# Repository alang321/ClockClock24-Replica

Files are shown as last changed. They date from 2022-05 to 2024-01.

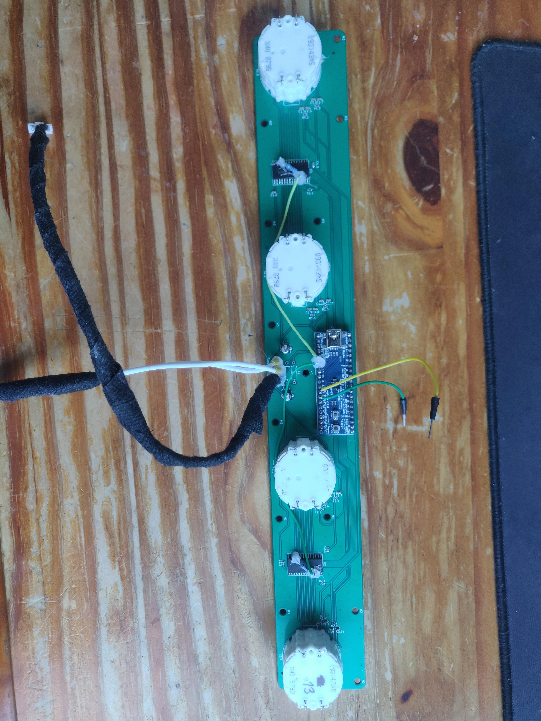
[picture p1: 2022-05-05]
Media/Photos of stepper module/module.jpg

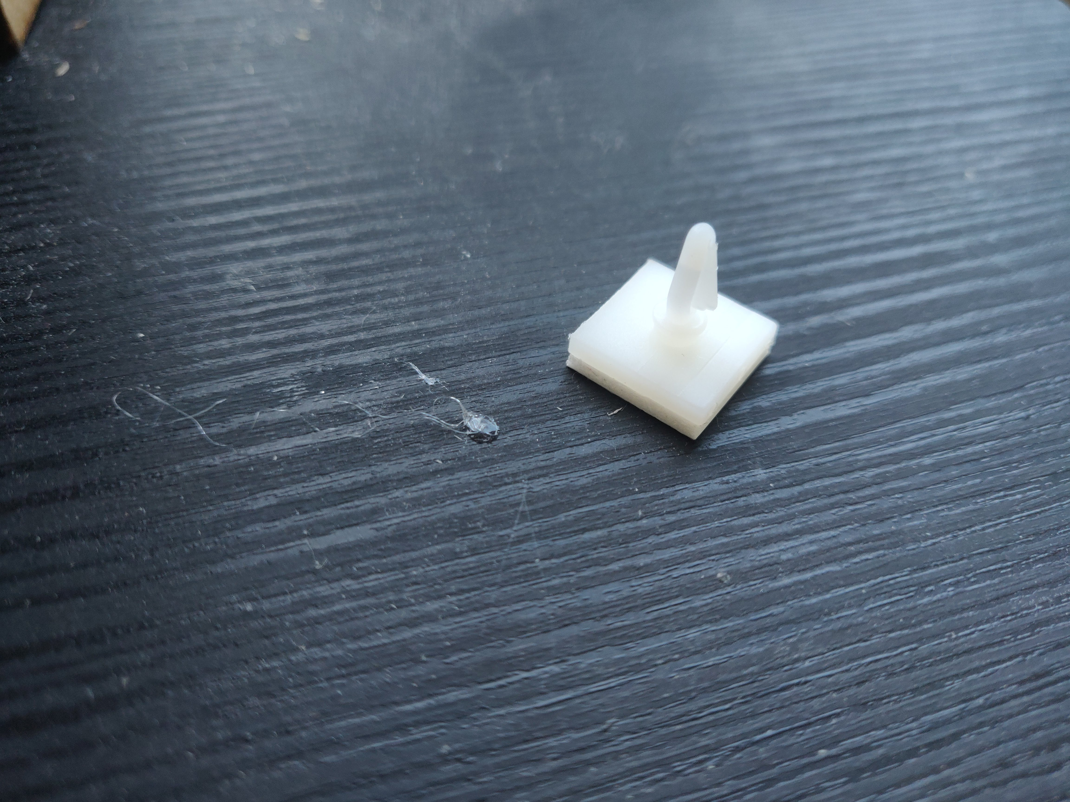
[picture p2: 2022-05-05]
Media/Photos of stepper module/pcb mount.jpg

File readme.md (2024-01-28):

# ClockClock 24 replica

Video of clock in action: https://photos.google.com/share/AF1QipM3veQpQ0XkVU6mXYjfI77cDL8gVcDZlROT0_qATZYPRnyIRZsuLHRsqtRsNTrixQ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

A clock consiting of 24 X40 stepper motors. There are 6 pcb where 4 of the X40 steppers are on a pcb. On each PCB 2 X40 (so 4 steppers, since X40 are dual axle) are controlled by a VID6606 stepper controller, so 2 VID6606 per PCB. These 2 are controlled by 1 MapleMini STM32F103. These 6 modules are controlled by a single RasberryPi Pico running MicroPython, this Pico communicates with the modules over I2C and also a DS3231 RTC for timekeeping. Additionally, as an optional addon a network model (a Pico W) can be added to get ITP time (This was added after everthing was finished so I didnt want to change the main control board to a Pico W). The clock works reliably with the newest addition of chekcsums and hasnt crashed since. Setting the time and display modes is done via a button panel of 4 buttons.

## Things to improve:
- The bus should be switched to CAN something else more robust then I2C, which is used here. I2C now works flawlessly for me but perhaps in a higher noise environment or over years errors would occur.
- Add pull down resistor for enable pin of vid 6606, connect to MCU pin (had to be botched in)
- Change microcontroller to smth cheaper/newer (RP2040?)
- Maybe switch to TMC2209 or smth for more silent driving (Some preliminary tests showed they do work with these steppers and are a bit more quiet, but they are much more expensive)

## Additional notes: 

- There was a plan to automatically zero the steppers with a small magnet and hall sensor but this was not implemented, but the sensor mountings are present on the PCB
- I lubricated the X40 steppers with SuperLube which did definitely reduce noise but this went back to normal levels after a few months.
- The main body is made of Korian which I had made by a professional using the drawing in the 3d parts folder
- Pointers where printed on a consumer FDM printer (Ender3V2) and where sanded and are friction fit.

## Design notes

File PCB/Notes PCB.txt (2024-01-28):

Things to improve:

Remove hall sensor functionality
Add can bus or smth, since i2c is not robust
Add pull down resistor for enable pin of vid 6606, connect to MCU pin
Change microcontroller to smth cheaper/newer (RP2040?)?
Add bus daisy chain connectors
Add better connector (instead of screw terminal)
Use pin 14 instead of pin 22 (if same MapleMini is used, gave some weird issues)

Maybe switch to TMC2209 or smth for more silent driving (Some preliminary tests showed they do work with these steppers and are a bit more quiet)

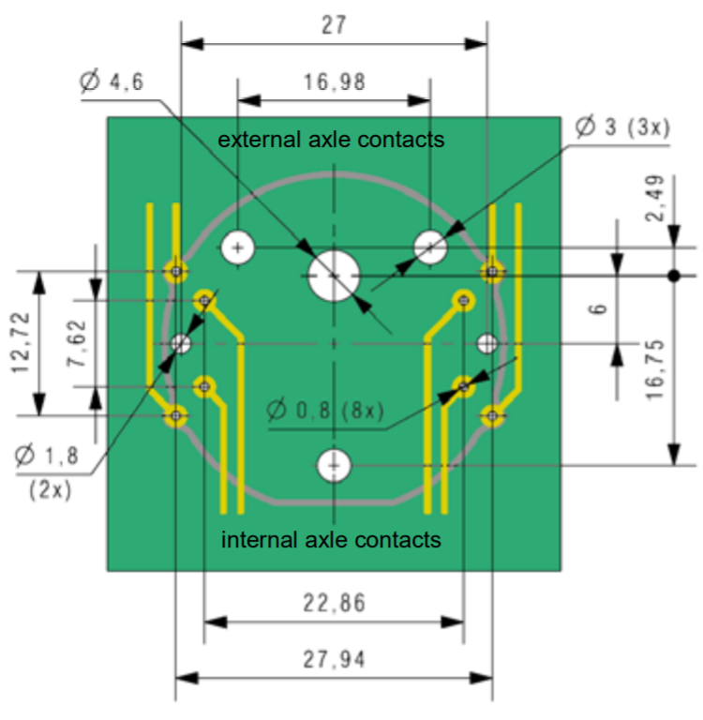
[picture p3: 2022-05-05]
Media/Reference photos/Screenshot 2021-03-22 151851.png

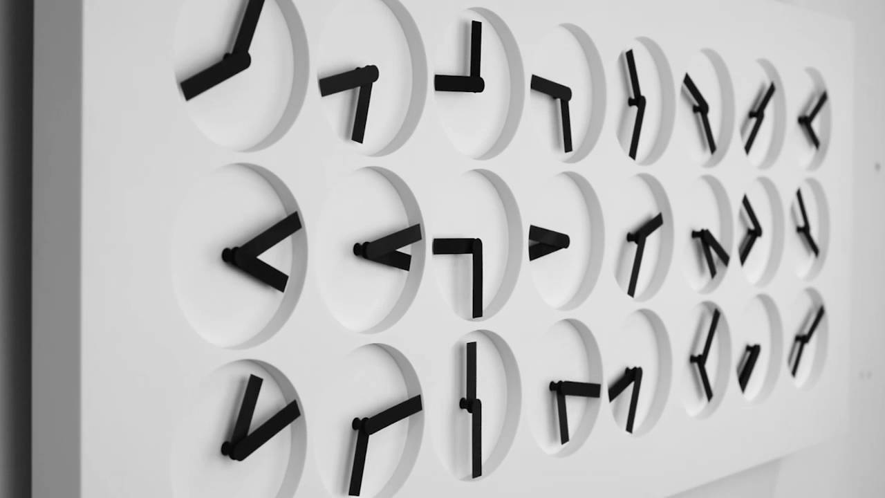
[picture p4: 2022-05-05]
Media/Reference photos/clock-clock-24-a-fascinating-kin.jpg

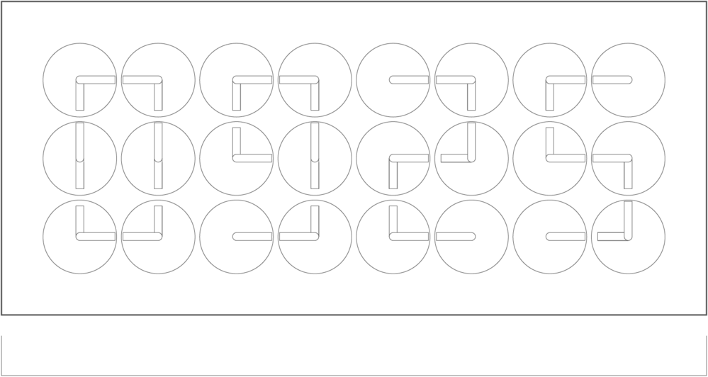
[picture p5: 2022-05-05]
Media/Reference photos/w_CC24_FRONT_spspec_900-x-400mm_1000x.png

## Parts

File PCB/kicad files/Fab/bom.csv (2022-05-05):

Comment | Designator | Footprint | LCSC Part Number
22 uF | C1.1,C2.1 | Capacitor_SMD:CP_Elec_4x5.3 | C134793
100 nF | C1.2,C1.3,C2.2,C2.3 | Capacitor_SMD:C_0603_1608Metric | C14663
4.7 nF | C1.4,C1.5,C1.6,C1.7,C1.8,C1.9,C2.4,C2.5,C2.6,C2.7,C2.8,C2.9,C1.10,C1.11,C2.10,C2.11 | Capacitor_SMD:C_0603_1608Metric | C53987
Conn_01x04_Female | J1 | Connector_PinHeader_2.54mm:PinHeader_1x04_P2.54mm_Vertical | C474922
1K2 | R1.1,R1.2,R1.3,R1.4,R1.5,R2.1,R2.2,R2.3,R2.4,R2.5 | Resistor_SMD:R_0603_1608Metric | C22765

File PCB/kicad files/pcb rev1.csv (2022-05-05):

Source: | C:\Users\muska\Desktop\pcb rev2\pcb rev1.sch
Date: | 27.05.2021 11:37:47
Tool: | Eeschema (5.1.10)-1
Generator: | C:\Program Files\KiCad\bin\scripting\plugins/bom_csv_grouped_by_value.py
Component Count: | 50
Individual Components:
Item | Qty | Reference(s) | Value | LibPart | Footprint | Datasheet | LCSC
 |  | A1 | Maple_Mini | MCU_Module:Maple_Mini | Module:Maple_Mini | http://docs.leaflabs.com/static.leaflabs.com/pub/leaflabs/maple-docs/0.0.12/hardware/maple-mini.html
 |  | C1.1 | 22 uF | Device:CP | Capacitor_SMD:CP_Elec_4x5.3 | ~ | C134793
 |  | C1.2 | 100 nF | Device:C | Capacitor_SMD:C_0603_1608Metric | ~ | C14663
 |  | C1.3 | 100 nF | Device:C | Capacitor_SMD:C_0603_1608Metric | ~ | C14663
 |  | C1.4 | 4.7 nF | Device:C | Capacitor_SMD:C_0603_1608Metric | ~ | C53987
 |  | C1.5 | 4.7 nF | Device:C | Capacitor_SMD:C_0603_1608Metric | ~ | C53987
 |  | C1.6 | 4.7 nF | Device:C | Capacitor_SMD:C_0603_1608Metric | ~ | C53987
 |  | C1.7 | 4.7 nF | Device:C | Capacitor_SMD:C_0603_1608Metric | ~ | C53987
 |  | C1.8 | 4.7 nF | Device:C | Capacitor_SMD:C_0603_1608Metric | ~ | C53987
 |  | C1.9 | 4.7 nF | Device:C | Capacitor_SMD:C_0603_1608Metric | ~ | C53987
 |  | C1.10 | 4.7 nF | Device:C | Capacitor_SMD:C_0603_1608Metric | ~ | C53987
 |  | C1.11 | 4.7 nF | Device:C | Capacitor_SMD:C_0603_1608Metric | ~ | C53987
 |  | C2.1 | 22 uF | Device:CP | Capacitor_SMD:CP_Elec_4x5.3 | ~ | C134793
 |  | C2.2 | 100 nF | Device:C | Capacitor_SMD:C_0603_1608Metric | ~ | C14663
 |  | C2.3 | 100 nF | Device:C | Capacitor_SMD:C_0603_1608Metric | ~ | C14663
 |  | C2.4 | 4.7 nF | Device:C | Capacitor_SMD:C_0603_1608Metric | ~ | C53987
 |  | C2.5 | 4.7 nF | Device:C | Capacitor_SMD:C_0603_1608Metric | ~ | C53987
 |  | C2.6 | 4.7 nF | Device:C | Capacitor_SMD:C_0603_1608Metric | ~ | C53987
 |  | C2.7 | 4.7 nF | Device:C | Capacitor_SMD:C_0603_1608Metric | ~ | C53987
 |  | C2.8 | 4.7 nF | Device:C | Capacitor_SMD:C_0603_1608Metric | ~ | C53987
 |  | C2.9 | 4.7 nF | Device:C | Capacitor_SMD:C_0603_1608Metric | ~ | C53987
 |  | C2.10 | 4.7 nF | Device:C | Capacitor_SMD:C_0603_1608Metric | ~ | C53987
 |  | C2.11 | 4.7 nF | Device:C | Capacitor_SMD:C_0603_1608Metric | ~ | C53987
 |  | H1.1L1 | TLE4905L | pcb-rev1-rescue:TLE4905L-Sensor_Magnetic | c40:PG-SSO-3-02 | https://sensing.honeywell.com/honeywell-sensing-nanopower-series-product-sheet-50095501-a-en.pdf
 |  | H1.1U1 | TLE4905L | pcb-rev1-rescue:TLE4905L-Sensor_Magnetic | c40:PG-SSO-3-02 | https://sensing.honeywell.com/honeywell-sensing-nanopower-series-product-sheet-50095501-a-en.pdf
 |  | H1.2L1 | TLE4905L | pcb-rev1-rescue:TLE4905L-Sensor_Magnetic | c40:PG-SSO-3-02 | https://sensing.honeywell.com/honeywell-sensing-nanopower-series-product-sheet-50095501-a-en.pdf
 |  | H1.2U1 | TLE4905L | pcb-rev1-rescue:TLE4905L-Sensor_Magnetic | c40:PG-SSO-3-02 | https://sensing.honeywell.com/honeywell-sensing-nanopower-series-product-sheet-50095501-a-en.pdf
 |  | H2.1L1 | TLE4905L | pcb-rev1-rescue:TLE4905L-Sensor_Magnetic | c40:PG-SSO-3-02 | https://sensing.honeywell.com/honeywell-sensing-nanopower-series-product-sheet-50095501-a-en.pdf
 |  | H2.1U1 | TLE4905L | pcb-rev1-rescue:TLE4905L-Sensor_Magnetic | c40:PG-SSO-3-02 | https://sensing.honeywell.com/honeywell-sensing-nanopower-series-product-sheet-50095501-a-en.pdf
 |  | H2.2L1 | TLE4905L | pcb-rev1-rescue:TLE4905L-Sensor_Magnetic | c40:PG-SSO-3-02 | https://sensing.honeywell.com/honeywell-sensing-nanopower-series-product-sheet-50095501-a-en.pdf
 |  | H2.2U2 | TLE4905L | pcb-rev1-rescue:TLE4905L-Sensor_Magnetic | c40:PG-SSO-3-02 | https://sensing.honeywell.com/honeywell-sensing-nanopower-series-product-sheet-50095501-a-en.pdf
 |  | J1 | Conn_01x04_Female | Connector:Conn_01x04_Female | Connector_PinHeader_2.54mm:PinHeader_1x04_P2.54mm_Vertical | ~ | C474922
 |  | R1 | 5K | Device:R | Resistor_THT:R_Axial_DIN0207_L6.3mm_D2.5mm_P10.16mm_Horizontal | ~
 |  | R1.1 | 1K2 | Device:R | Resistor_SMD:R_0603_1608Metric | ~ | C22765
 |  | R1.2 | 1K2 | Device:R | Resistor_SMD:R_0603_1608Metric | ~ | C22765
 |  | R1.3 | 1K2 | Device:R | Resistor_SMD:R_0603_1608Metric | ~ | C22765
 |  | R1.4 | 1K2 | Device:R | Resistor_SMD:R_0603_1608Metric | ~ | C22765
 |  | R1.5 | 1K2 | Device:R | Resistor_SMD:R_0603_1608Metric | ~ | C22765
 |  | R2 | 5K | Device:R | Resistor_THT:R_Axial_DIN0207_L6.3mm_D2.5mm_P10.16mm_Horizontal | ~
 |  | R2.1 | 1K2 | Device:R | Resistor_SMD:R_0603_1608Metric | ~ | C22765
 |  | R2.2 | 1K2 | Device:R | Resistor_SMD:R_0603_1608Metric | ~ | C22765
 |  | R2.3 | 1K2 | Device:R | Resistor_SMD:R_0603_1608Metric | ~ | C22765
 |  | R2.4 | 1K2 | Device:R | Resistor_SMD:R_0603_1608Metric | ~ | C22765
 |  | R2.5 | 1K2 | Device:R | Resistor_SMD:R_0603_1608Metric | ~ | C22765
 |  | U1 | VID66-06 | pcb-rev1-rescue:VID66-06-Driver_Motor | Package_SO:SOP-28
 |  | U2 | VID66-06 | pcb-rev1-rescue:VID66-06-Driver_Motor | Package_SO:SOP-28
 |  | X1.1 | X40 | pcb-rev1-rescue:X40-Driver_Motor | c40:X40
 |  | X1.2 | X40 | pcb-rev1-rescue:X40-Driver_Motor | c40:X40
 |  | X2.1 | X40 | pcb-rev1-rescue:X40-Driver_Motor | c40:X40
 |  | X2.2 | X40 | pcb-rev1-rescue:X40-Driver_Motor | c40:X40
Collated Components:
Item | Qty | Reference(s) | Value | LibPart | Footprint | Datasheet | LCSC
1 | 1 | A1 | Maple_Mini | MCU_Module:Maple_Mini | Module:Maple_Mini | http://docs.leaflabs.com/static.leaflabs.com/pub/leaflabs/maple-docs/0.0.12/hardware/maple-mini.html
2 | 2 | C1.1, C2.1 | 22 uF | Device:CP | Capacitor_SMD:CP_Elec_4x5.3 | ~ | C134793
3 | 4 | C1.2, C1.3, C2.2, C2.3 | 100 nF | Device:C | Capacitor_SMD:C_0603_1608Metric | ~ | C14663
4 | 16 | C1.4, C1.5, C1.6, C1.7, C1.8, C1.9, C1.10, C1.11, C2.4, C2.5, C2.6, C2.7, C2.8, C2.9, C2.10, C2.11 | 4.7 nF | Device:C | Capacitor_SMD:C_0603_1608Metric | ~ | C53987
5 | 8 | H1.1L1, H1.1U1, H1.2L1, H1.2U1, H2.1L1, H2.1U1, H2.2L1, H2.2U2 | TLE4905L | pcb-rev1-rescue:TLE4905L-Sensor_Magnetic | c40:PG-SSO-3-02 | https://sensing.honeywell.com/honeywell-sensing-nanopower-series-product-sheet-50095501-a-en.pdf
6 | 1 | J1 | Conn_01x04_Female | Connector:Conn_01x04_Female | Connector_PinHeader_2.54mm:PinHeader_1x04_P2.54mm_Vertical | ~ | C474922
7 | 2 | R1, R2 | 5K | Device:R | Resistor_THT:R_Axial_DIN0207_L6.3mm_D2.5mm_P10.16mm_Horizontal | ~
8 | 10 | R1.1, R1.2, R1.3, R1.4, R1.5, R2.1, R2.2, R2.3, R2.4, R2.5 | 1K2 | Device:R | Resistor_SMD:R_0603_1608Metric | ~ | C22765
9 | 2 | U1, U2 | VID66-06 | pcb-rev1-rescue:VID66-06-Driver_Motor | Package_SO:SOP-28
10 | 4 | X1.1, X1.2, X2.1, X2.2 | X40 | pcb-rev1-rescue:X40-Driver_Motor | c40:X40

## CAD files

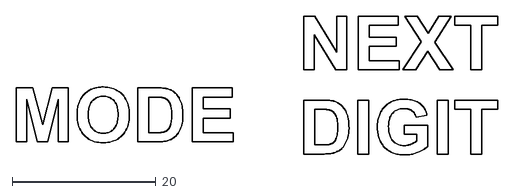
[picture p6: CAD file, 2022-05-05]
3d models/button plate/MODE.dxf
67.0 x 19.3

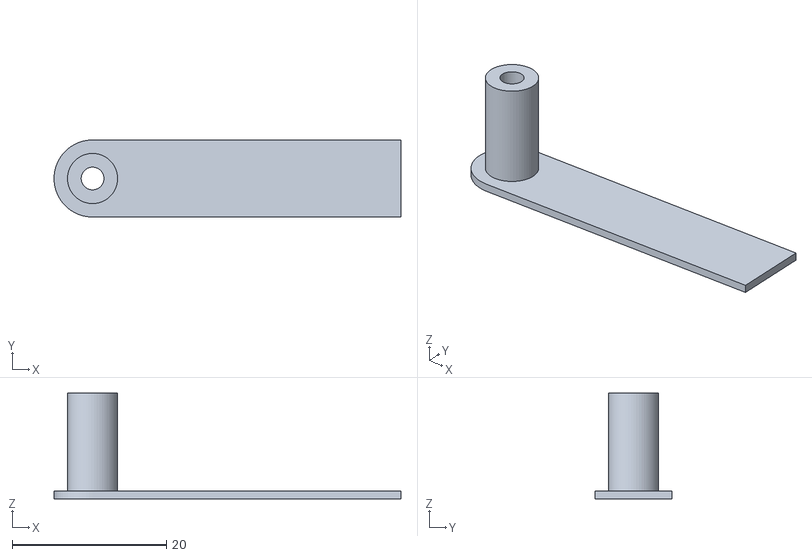
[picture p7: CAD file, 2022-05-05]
3d models/pointer/pointer HP MJF (never tested)/pointer_hour.stl
45.0 x 10.0 x 13.7

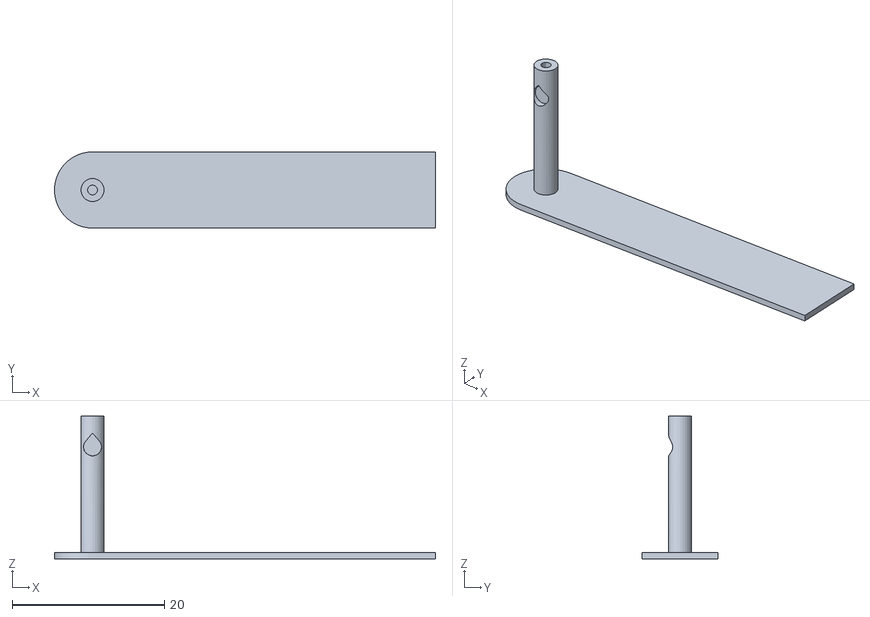
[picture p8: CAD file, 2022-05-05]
3d models/pointer/pointer resin rev 1 (never printed)/STL/minuten.stl
50.0 x 10.0 x 18.7

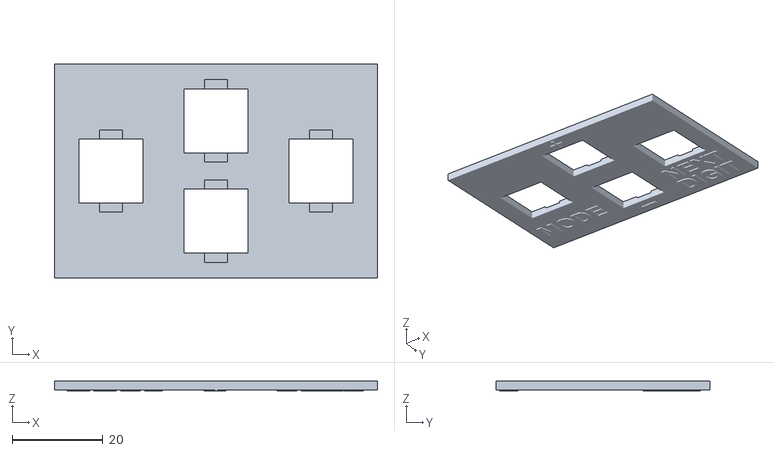
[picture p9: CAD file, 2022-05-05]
3d models/button plate/button_plate.stl
71.1 x 47.0 x 2.30

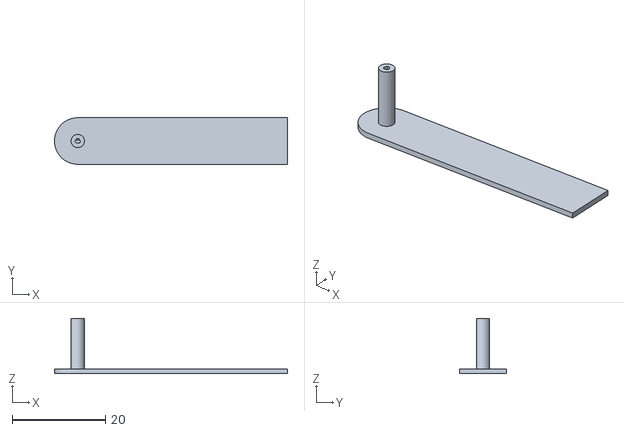
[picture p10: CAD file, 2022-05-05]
3d models/pointer/pointer HP MJF (never tested)/pointer_minute.stl
50.0 x 10.0 x 11.9

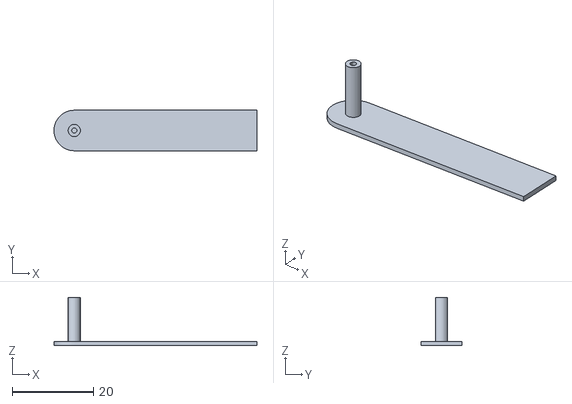
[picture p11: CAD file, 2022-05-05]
3d models/pointer/pointer no magnet (used in my version)/STL/minuten.stl
50.0 x 10.0 x 11.9

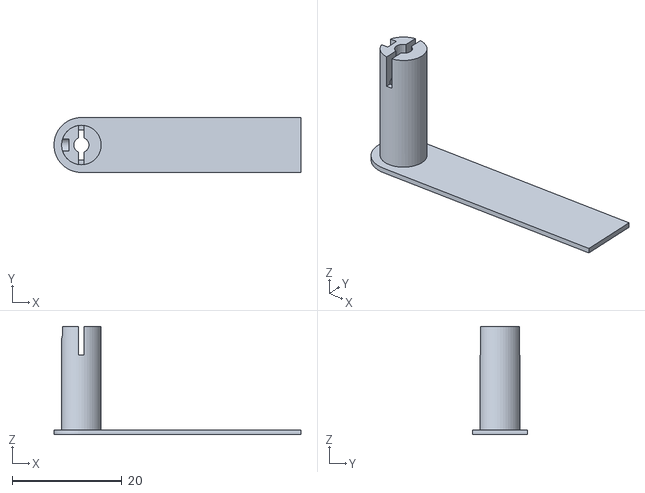
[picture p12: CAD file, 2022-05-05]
3d models/pointer/pointer resin rev 1 (never printed)/STL/stunden.stl
45.0 x 10.0 x 19.7

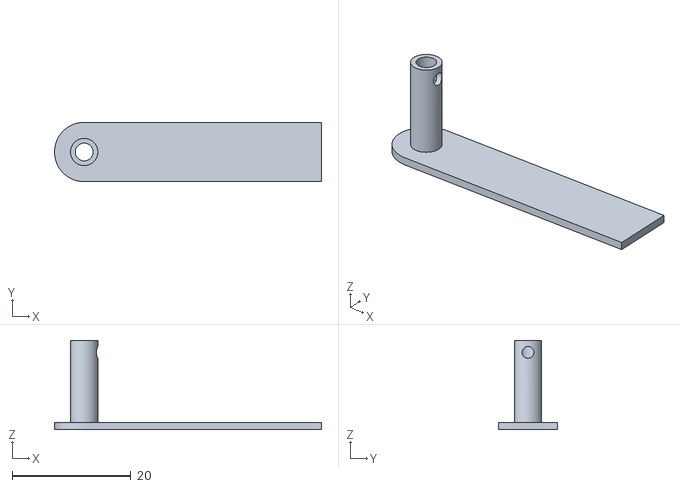
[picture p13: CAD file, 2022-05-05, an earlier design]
3d models/pointer/pointer with magnet/uhrzeiger rev 2/STL/stunden.stl
45.0 x 10.0 x 15.0

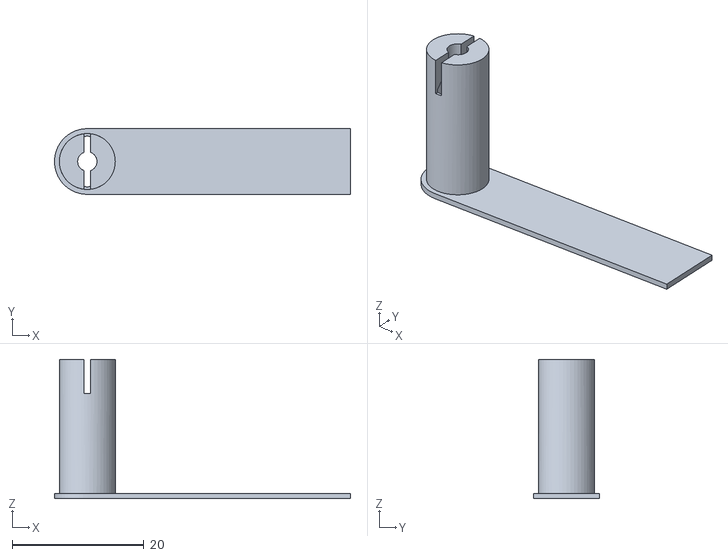
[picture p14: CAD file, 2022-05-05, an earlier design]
3d models/pointer/pointer with magnet/uhrzeiger rev 4/STL/stunden.stl
45.0 x 10.0 x 21.2

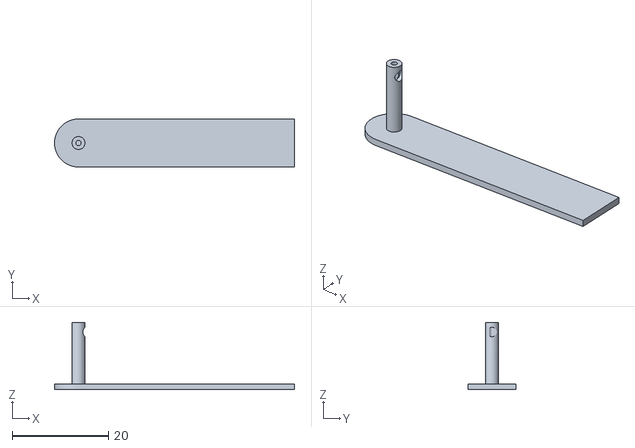
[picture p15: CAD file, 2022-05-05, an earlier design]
3d models/pointer/pointer with magnet/uhrzeiger rev 2/STL/minuten.stl
50.0 x 10.0 x 14.0

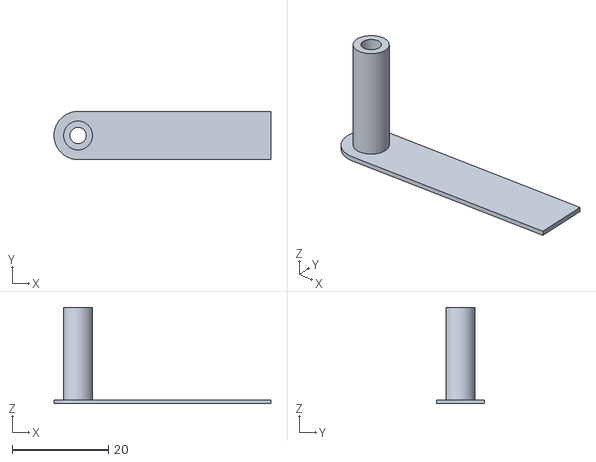
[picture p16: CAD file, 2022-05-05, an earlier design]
3d models/pointer/pointer with magnet/uhrzeiger rev 3/STL/stunden.stl
45.0 x 10.0 x 20.0

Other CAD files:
3d models/pointer/pointer no magnet (used in my version)/STL/stunden.stl
3d models/pointer/pointer with magnet/uhrzeiger rev 3/STL/minuten.stl
3d models/pointer/pointer with magnet/uhrzeiger rev 4/STL/minuten.stl
3d models/Other clock parts/Clockface with steppers and pcbs.CATProduct
3d models/Other clock parts/PCB with X40 assemblies.CATProduct
3d models/Other clock parts/Pcb.CATPart
3d models/Other clock parts/X40.CATPart
3d models/Other clock parts/clockback rim.CATPart
3d models/Other clock parts/clockface.CATPart
3d models/Other clock parts/x40 with pointers.CATProduct
3d models/button plate/plate.CATPart
3d models/pointer/pointer no magnet (used in my version)/CAD/Assembly.CATProduct
3d models/pointer/pointer no magnet (used in my version)/CAD/minuten.CATPart
3d models/pointer/pointer no magnet (used in my version)/CAD/stunden.CATPart
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

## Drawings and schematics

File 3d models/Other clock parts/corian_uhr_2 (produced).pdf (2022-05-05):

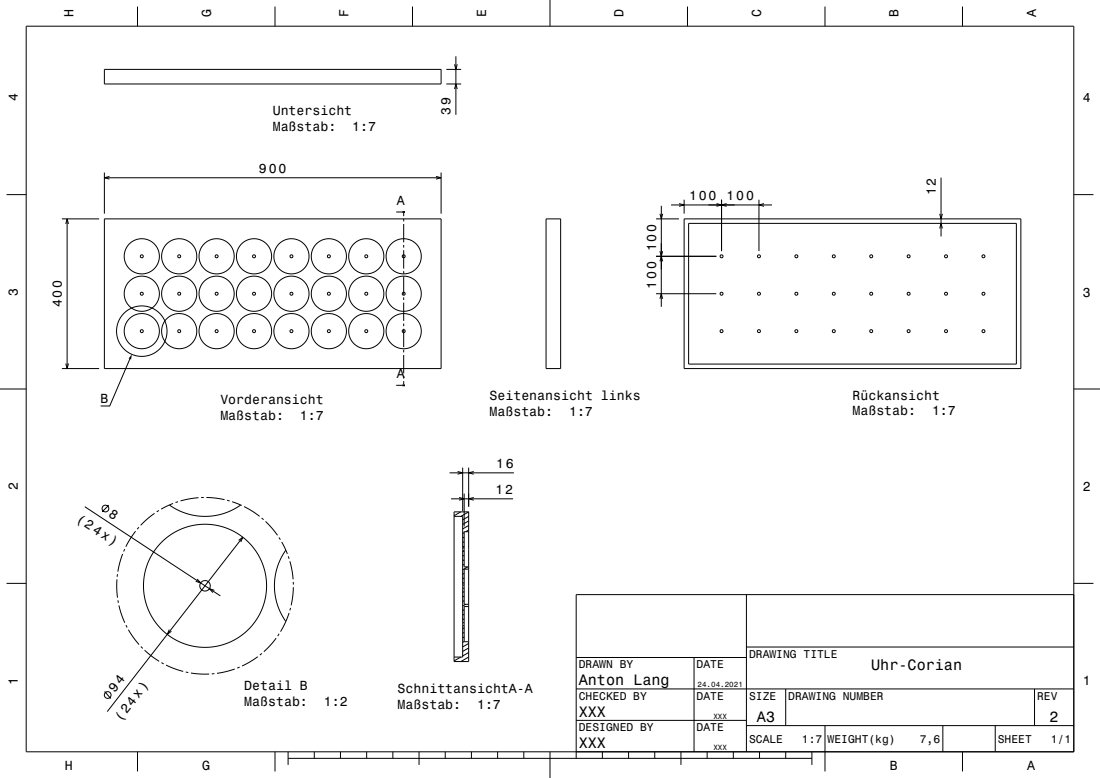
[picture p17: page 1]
DRAWING TITLE; Maßstab: 1:7; Seitenansicht links; Detail B Maßstab: 1:2

DRAWN BY Anton Lang | DATE 24.04.2021

CHECKED BY XXX | DATE XXX | SIZE A3 | DRAWING NUMBER | REV 2

DESIGNED BY XXX | DATE XXX

SCALE 1:7 | WEIGHT(kg) 7,6 | SHEET 1/1

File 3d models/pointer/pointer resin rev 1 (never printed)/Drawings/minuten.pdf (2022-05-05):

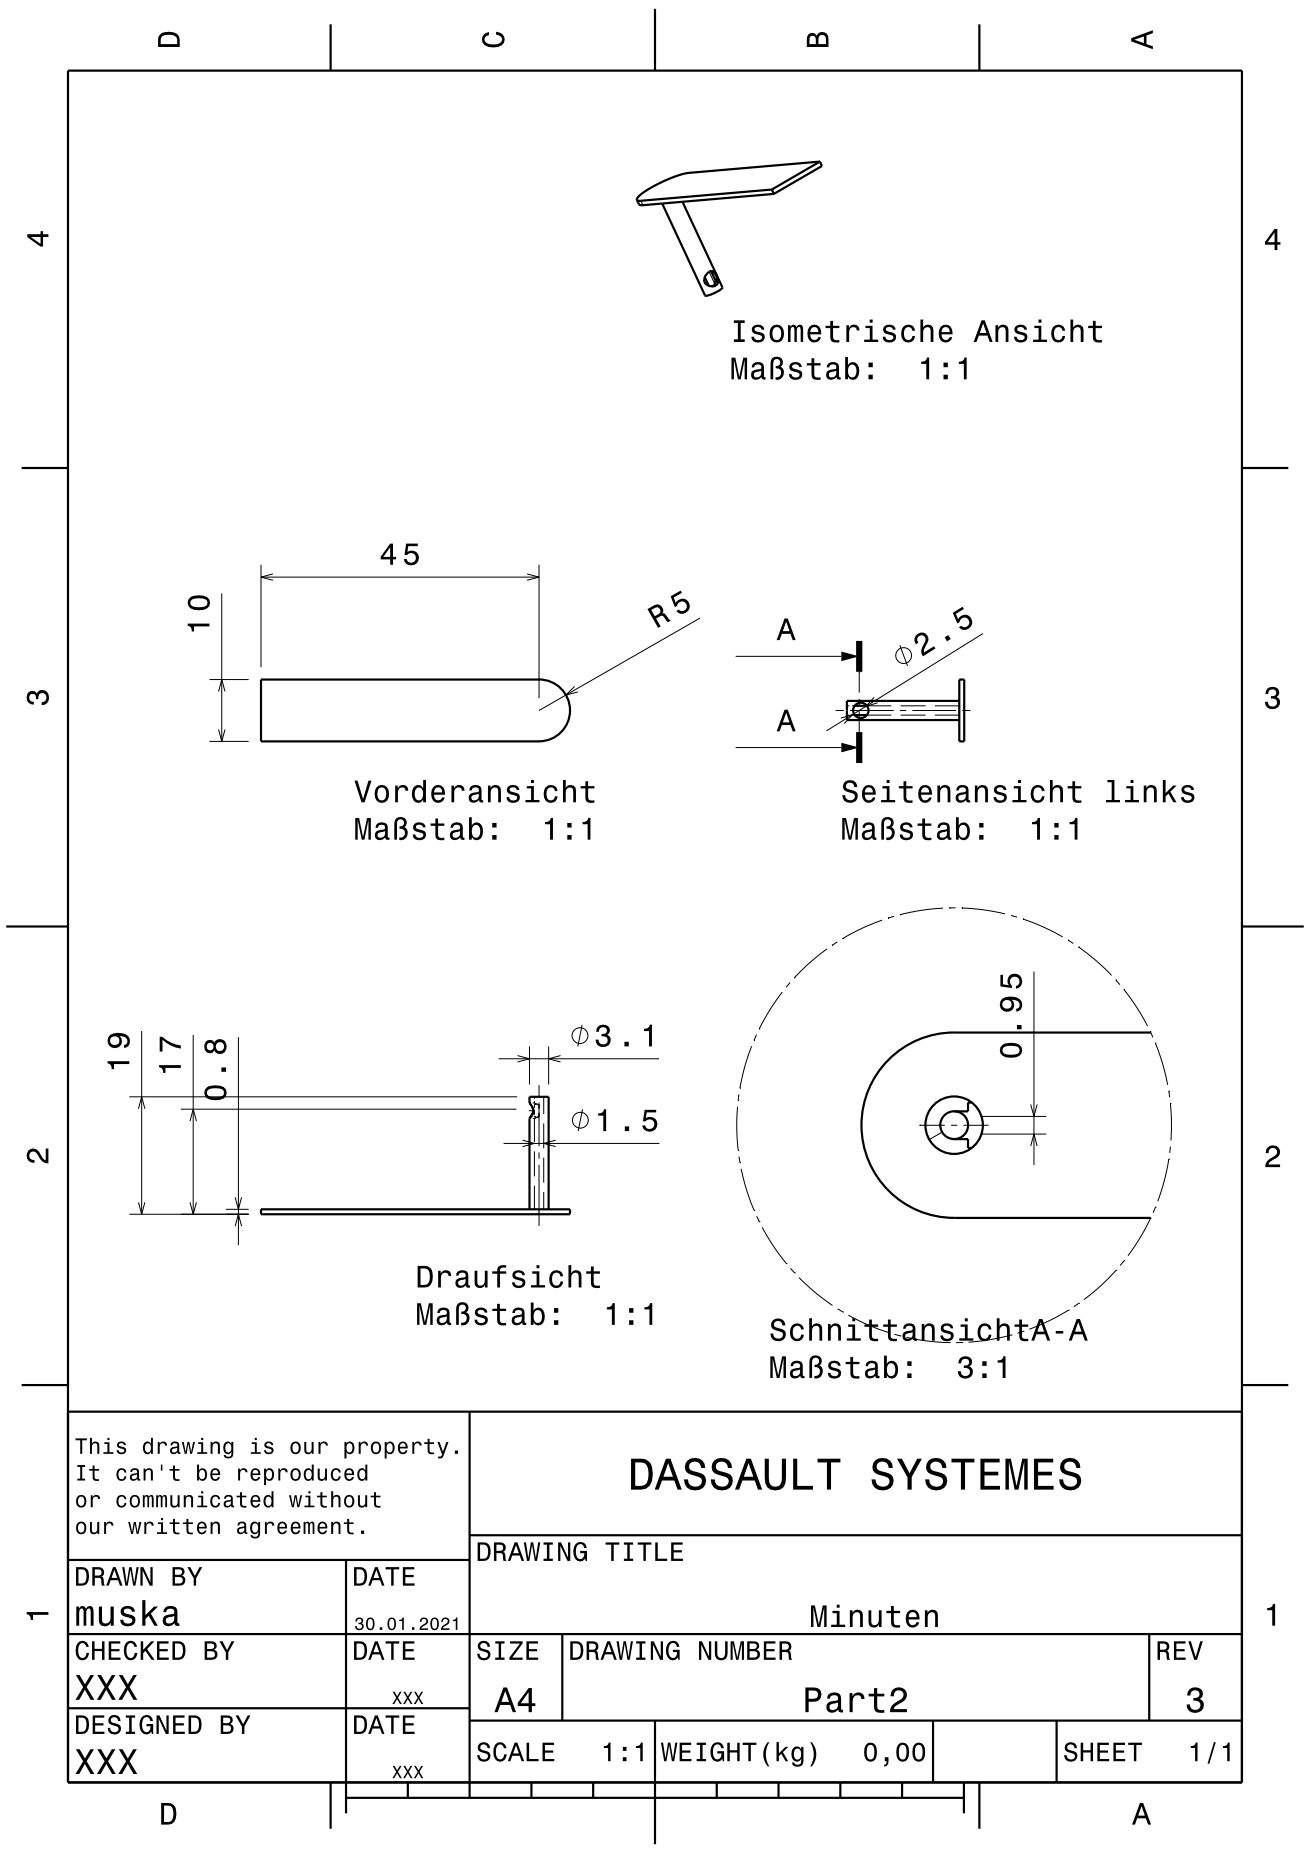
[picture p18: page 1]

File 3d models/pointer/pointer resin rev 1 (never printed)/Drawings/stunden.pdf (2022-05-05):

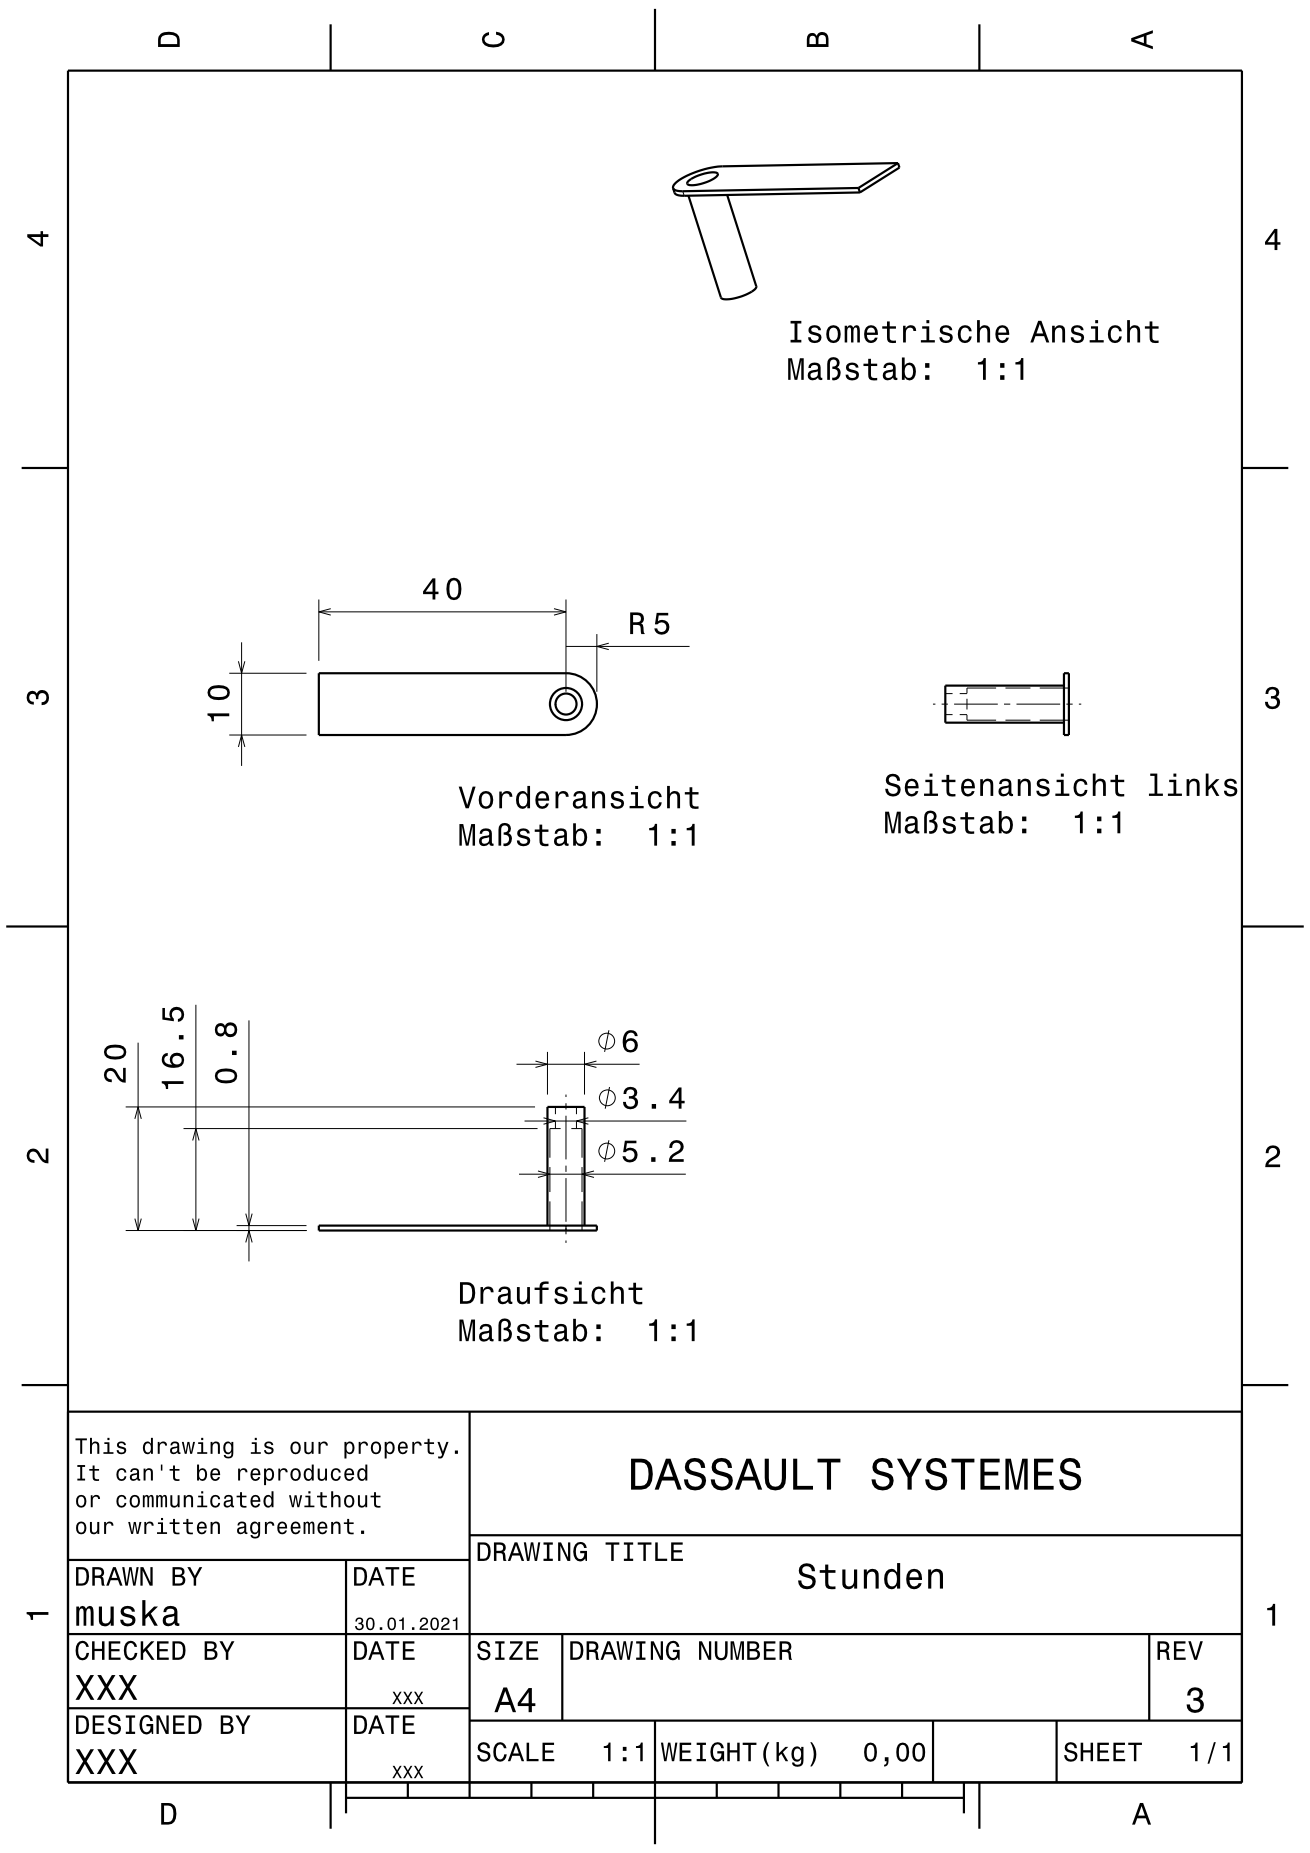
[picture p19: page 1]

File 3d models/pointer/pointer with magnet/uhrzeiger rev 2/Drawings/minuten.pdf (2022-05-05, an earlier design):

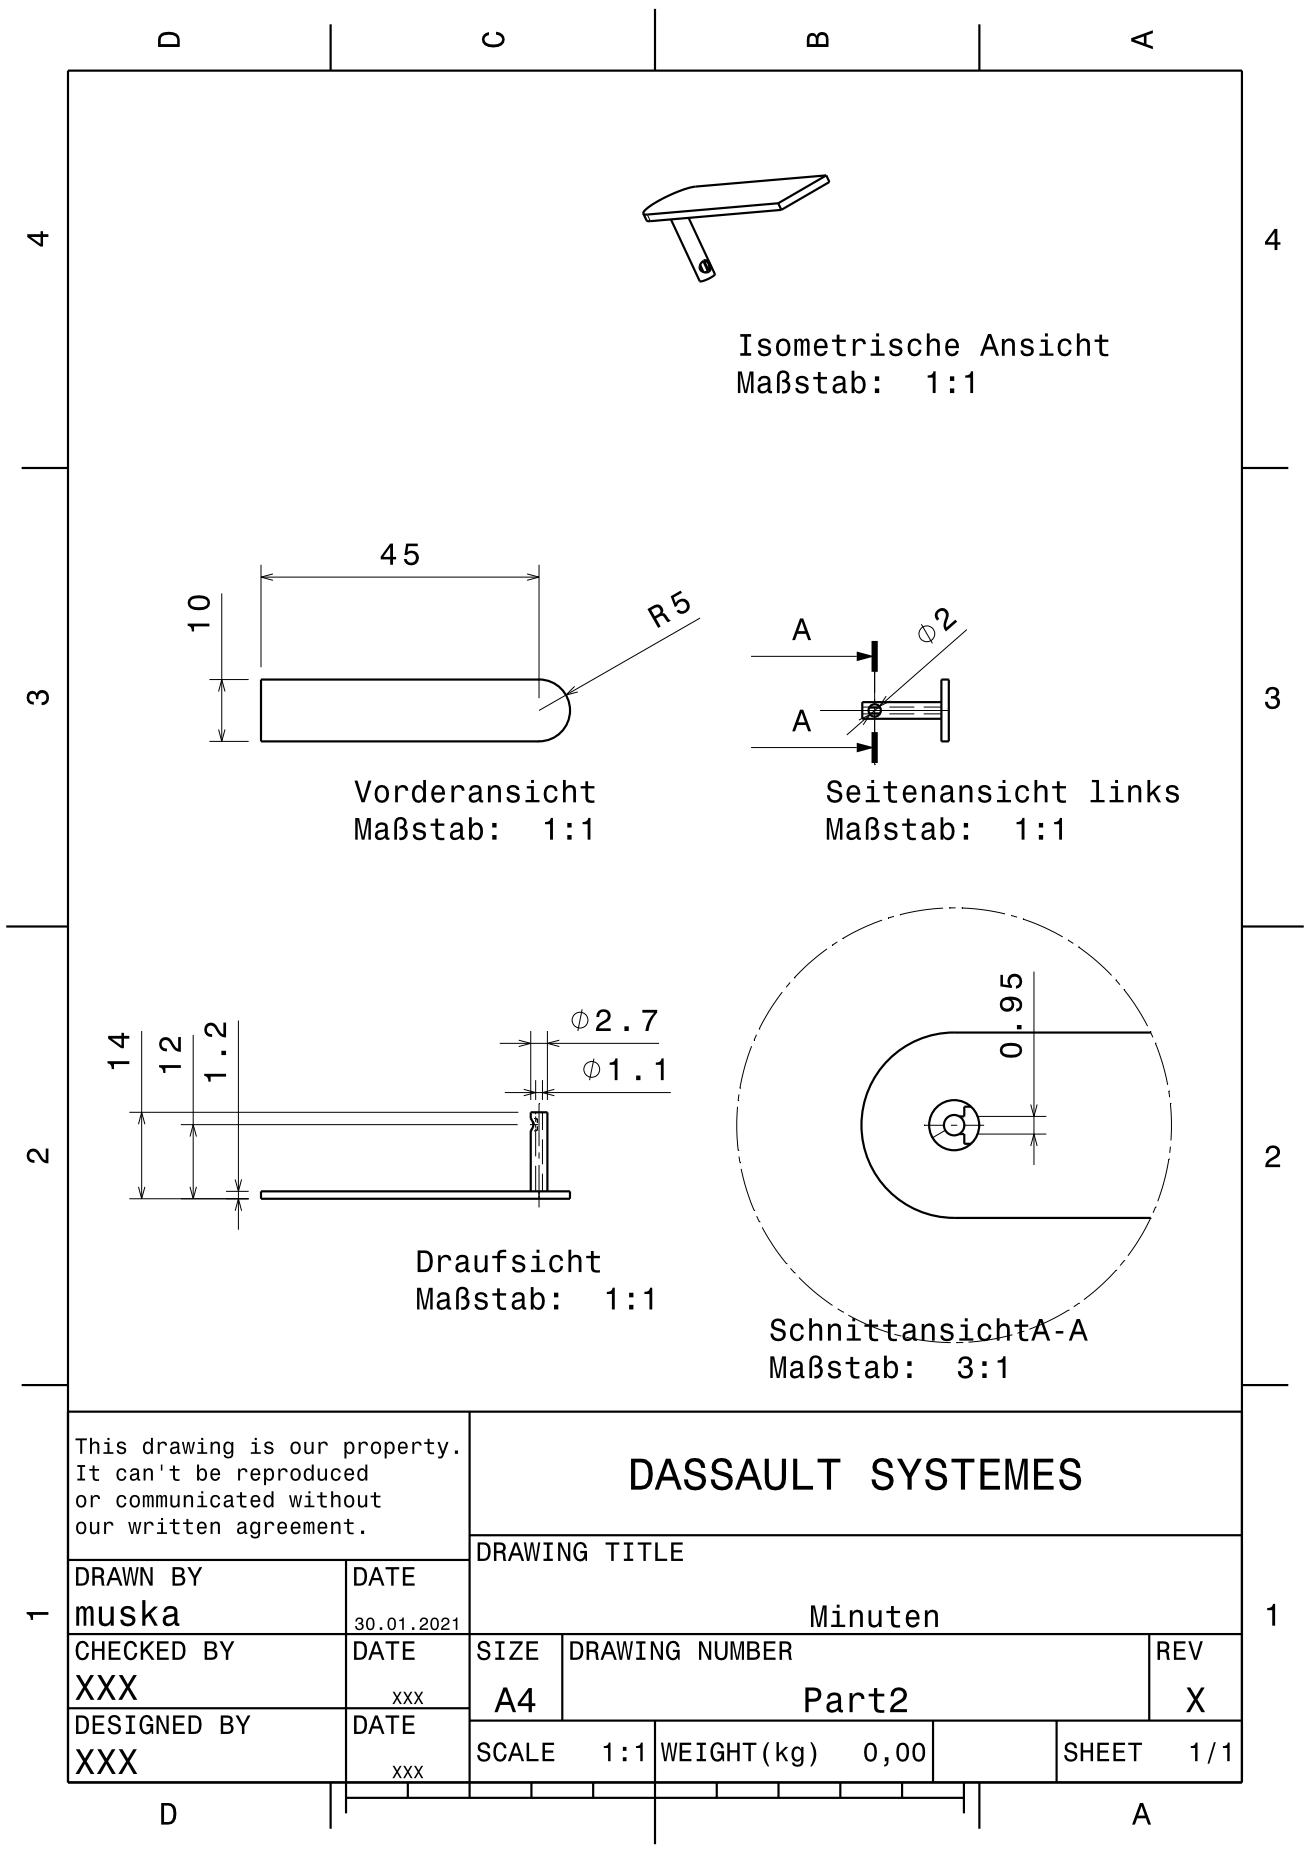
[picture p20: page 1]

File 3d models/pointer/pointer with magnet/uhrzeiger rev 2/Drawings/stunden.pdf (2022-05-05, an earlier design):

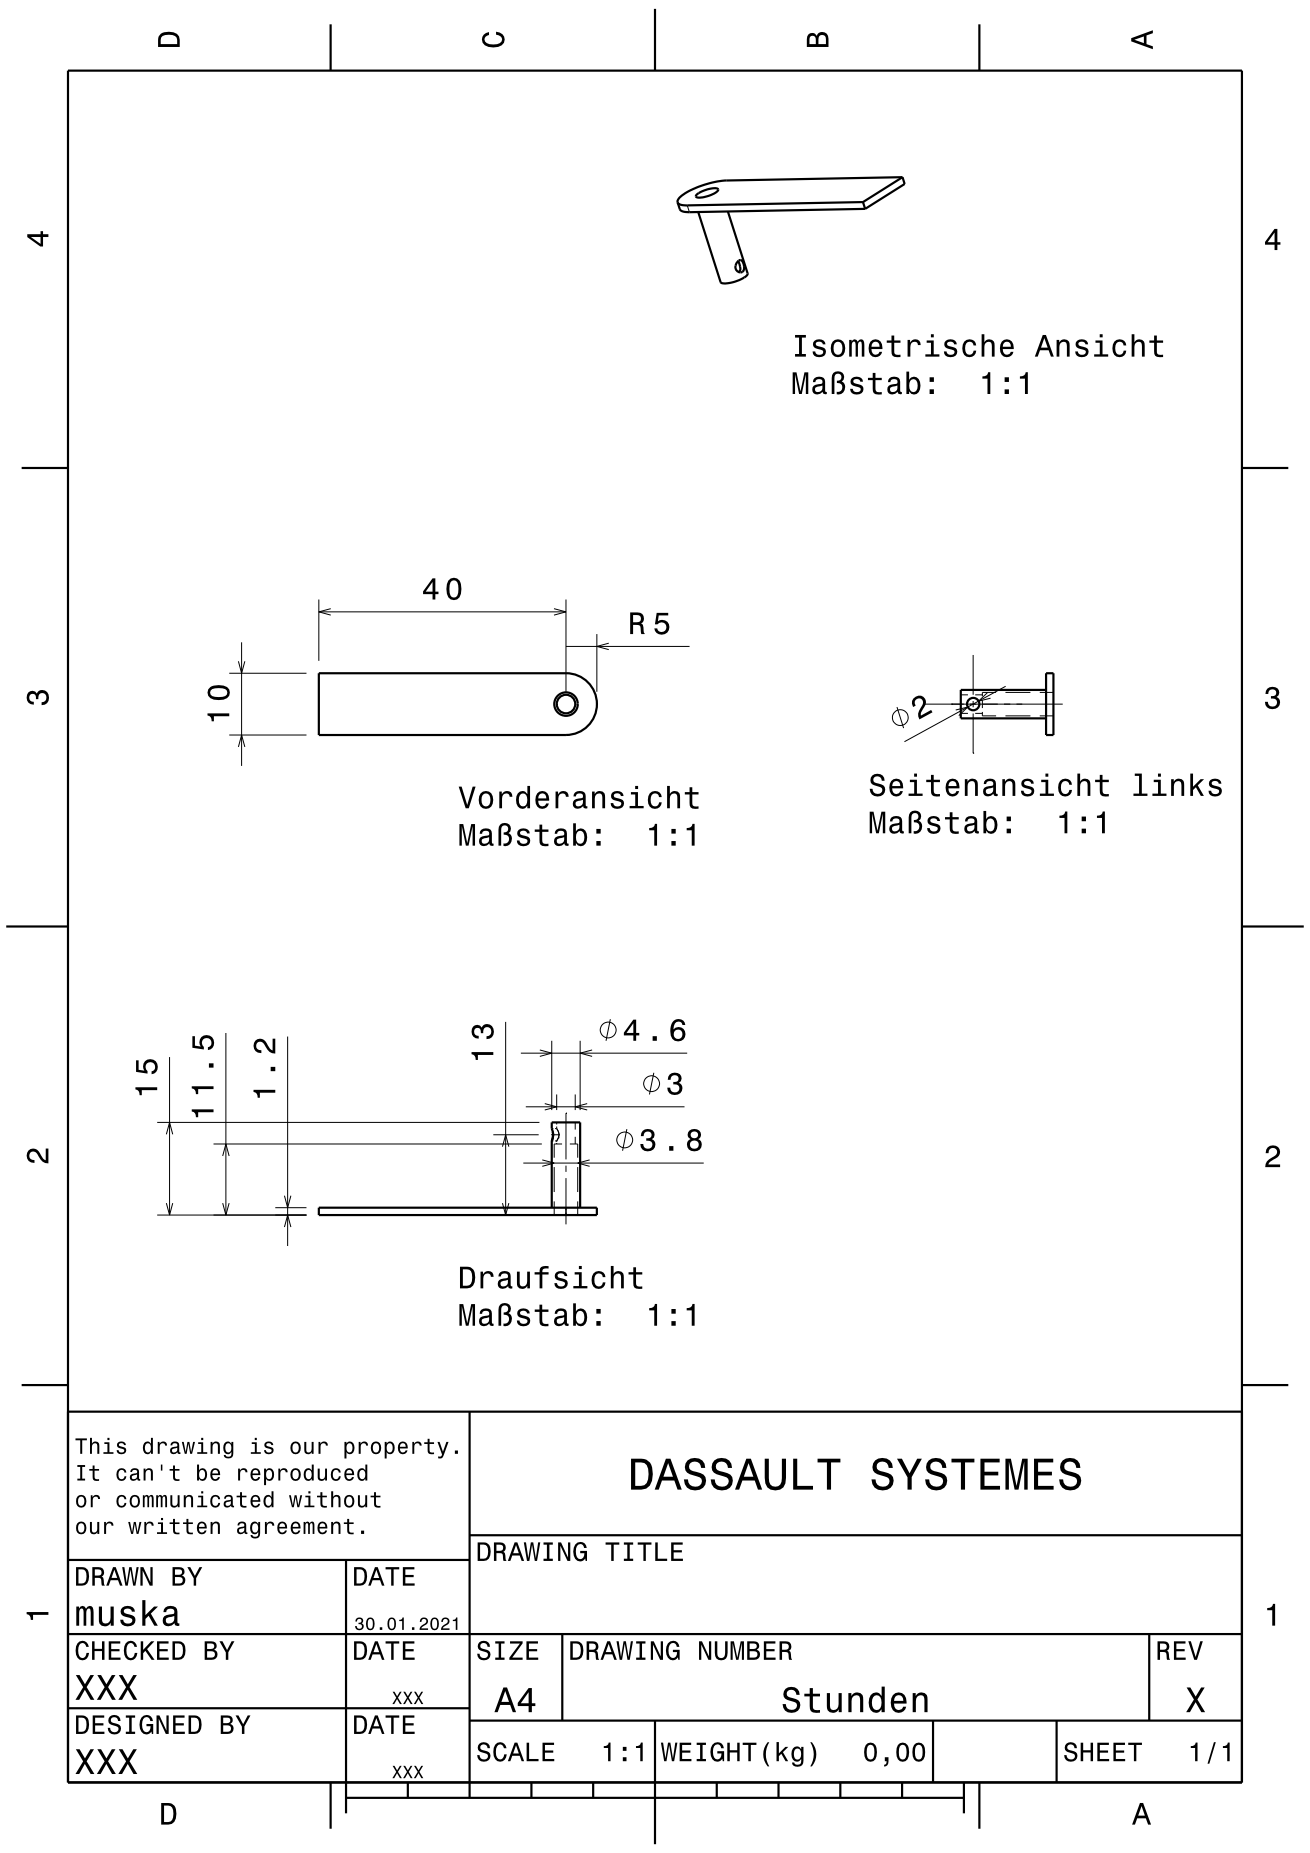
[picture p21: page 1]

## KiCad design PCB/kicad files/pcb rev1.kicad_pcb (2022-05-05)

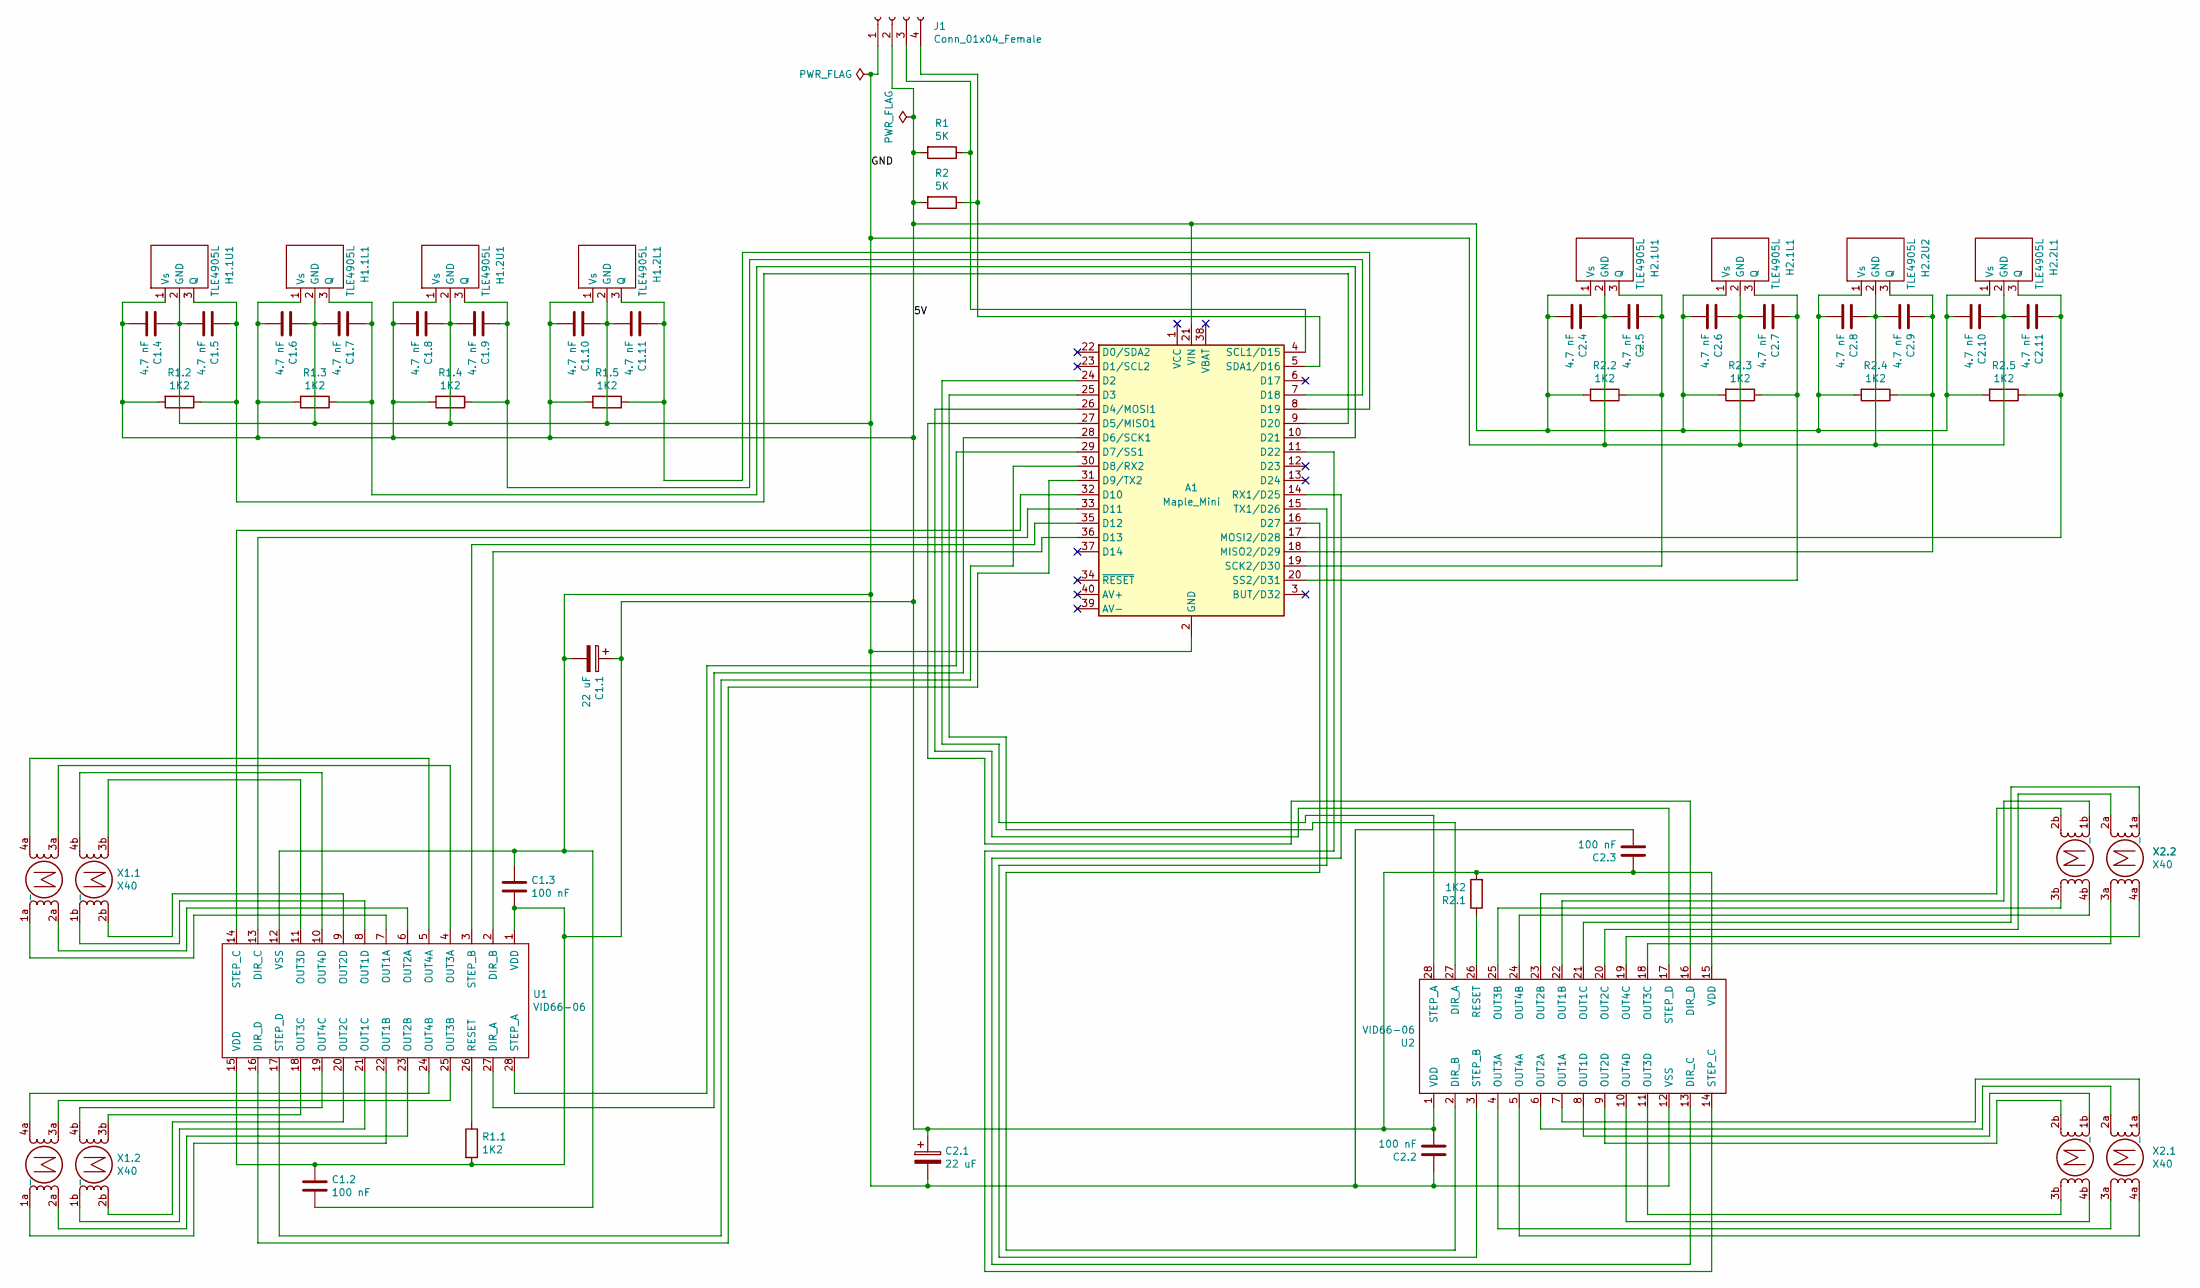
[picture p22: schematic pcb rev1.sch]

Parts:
A1: Maple_Mini
C1.1, C2.1: 22 uF; CP_Elec_4x5.3; LCSC C134793
C1.2, C1.3, C2.2, C2.3: 100 nF; C_0603_1608Metric; LCSC C14663
C1.4, C1.5, C1.6, C1.7, C1.8, C1.9, C1.10, C1.11, C2.4, C2.5, C2.6, C2.7, C2.8, C2.9, C2.10, C2.11: 4.7 nF; C_0603_1608Metric; LCSC C53987
H1.1L1, H1.1U1, H1.2L1, H1.2U1, H2.1L1, H2.1U1, H2.2L1, H2.2U2: TLE4905L; PG-SSO-3-02
J1: Conn_01x04_Female; PinHeader_1x04_P2.54mm_Vertical; LCSC C474922
R1, R2: 5K; R_Axial_DIN0207_L6.3mm_D2.5mm_P10.16mm_Horizontal
R1.1, R1.2, R1.3, R1.4, R1.5, R2.1, R2.2, R2.3, R2.4, R2.5: 1K2; R_0603_1608Metric; LCSC C22765
U1, U2: VID66-06; SOP-28
X1.1, X1.2, X2.1, X2.2: X40

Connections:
/5V: A1.21 (VIN), C1.1.1, C1.2.1, C1.3.1, C1.4.1, C1.6.1, C1.8.1, C1.10.1, C2.1.1, C2.2.1, C2.3.1, C2.4.1, C2.6.1, C2.8.1, C2.10.1, H1.1L1.1 (Vs), H1.1U1.1 (Vs), H1.2L1.1 (Vs), H1.2U1.1 (Vs), H2.1L1.1 (Vs), H2.1U1.1 (Vs), H2.2L1.1 (Vs), H2.2U2.1 (Vs), J1.2, R1.2, R1.1.2, R1.2.2, R1.3.2, R1.4.2, R1.5.2, R2.2, R2.1.2, R2.2.2, R2.3.2, R2.4.2, R2.5.2, U1.1 (VDD), U1.15 (VDD), U2.1 (VDD), U2.15 (VDD)
/GND: A1.2 (GND), C1.1.2, C1.2.2, C1.3.2, C1.4.2, C1.5.1, C1.6.2, C1.7.1, C1.8.2, C1.9.1, C1.10.2, C1.11.1, C2.1.2, C2.2.2, C2.3.2, C2.4.2, C2.5.1, C2.6.2, C2.7.1, C2.8.2, C2.9.1, C2.10.2, C2.11.1, H1.1L1.2 (GND), H1.1U1.2 (GND), H1.2L1.2 (GND), H1.2U1.2 (GND), H2.1L1.2 (GND), H2.1U1.2 (GND), H2.2L1.2 (GND), H2.2U2.2 (GND), J1.1, U1.12 (VSS), U2.12 (VSS)
unnamed: A1.4 (SCL1/D15), J1.3, R1.1
unnamed: A1.5 (SDA1/D16), J1.4, R2.1
unnamed: A1.7 (D18), C1.9.2, H1.2U1.3 (Q), R1.4.1
unnamed: A1.8 (D19), C1.11.2, H1.2L1.3 (Q), R1.5.1
unnamed: A1.9 (D20), C1.5.2, H1.1U1.3 (Q), R1.2.1
unnamed: A1.10 (D21), C1.7.2, H1.1L1.3 (Q), R1.3.1
unnamed: A1.11 (D22), U2.14 (STEP_C)
unnamed: A1.14 (RX1/D25), U2.13 (DIR_C)
unnamed: A1.15 (TX1/D26), U2.3 (STEP_B)
unnamed: A1.16 (D27), U2.2 (DIR_B)
unnamed: A1.17 (MOSI2/D28), C2.11.2, H2.2L1.3 (Q), R2.5.1
unnamed: A1.18 (MISO2/D29), C2.9.2, H2.2U2.3 (Q), R2.4.1
unnamed: A1.19 (SCK2/D30), C2.5.2, H2.1U1.3 (Q), R2.2.1
unnamed: A1.20 (SS2/D31), C2.7.2, H2.1L1.3 (Q), R2.3.1
unnamed: A1.24 (D2), U2.28 (STEP_A)
unnamed: A1.25 (D3), U2.27 (DIR_A)
unnamed: A1.26 (D4/MOSI1), U2.17 (STEP_D)
unnamed: A1.27 (D5/MISO1), U2.16 (DIR_D)
unnamed: A1.28 (D6/SCK1), U1.27 (DIR_A)
unnamed: A1.29 (D7/SS1), U1.28 (STEP_A)
unnamed: A1.30 (D8/RX2), U1.17 (STEP_D)
unnamed: A1.31 (D9/TX2), U1.16 (DIR_D)
unnamed: A1.32 (D10), U1.14 (STEP_C)
unnamed: A1.33 (D11), U1.13 (DIR_C)
unnamed: A1.35 (D12), U1.3 (STEP_B)
unnamed: A1.36 (D13), U1.2 (DIR_B)
unnamed: R1.1.1, U1.26 (RESET)
unnamed: R2.1.1, U2.26 (RESET)
unnamed: U1.4 (OUT3A), X1.1.3a
unnamed: U1.5 (OUT4A), X1.1.4a
unnamed: U1.6 (OUT2A), X1.1.2a
unnamed: U1.7 (OUT1A), X1.1.1a (-)
unnamed: U1.8 (OUT1D), X1.1.1b (-)
unnamed: U1.9 (OUT2D), X1.1.2b
unnamed: U1.10 (OUT4D), X1.1.4b
unnamed: U1.11 (OUT3D), X1.1.3b
unnamed: U1.18 (OUT3C), X1.2.3b
unnamed: U1.19 (OUT4C), X1.2.4b
unnamed: U1.20 (OUT2C), X1.2.2b
unnamed: U1.21 (OUT1C), X1.2.1b (-)
unnamed: U1.22 (OUT1B), X1.2.1a (-)
unnamed: U1.23 (OUT2B), X1.2.2a
unnamed: U1.24 (OUT4B), X1.2.4a
unnamed: U1.25 (OUT3B), X1.2.3a
unnamed: U2.4 (OUT3A), X2.1.3a
unnamed: U2.5 (OUT4A), X2.1.4a
unnamed: U2.6 (OUT2A), X2.1.2a
unnamed: U2.7 (OUT1A), X2.1.1a (-)
unnamed: U2.8 (OUT1D), X2.1.1b (-)
unnamed: U2.9 (OUT2D), X2.1.2b
unnamed: U2.10 (OUT4D), X2.1.4b
unnamed: U2.11 (OUT3D), X2.1.3b
unnamed: U2.18 (OUT3C), X2.2.3a
unnamed: U2.19 (OUT4C), X2.2.4a
unnamed: U2.20 (OUT2C), X2.2.2a
unnamed: U2.21 (OUT1C), X2.2.1a (-)
unnamed: U2.22 (OUT1B), X2.2.1b (-)
unnamed: U2.23 (OUT2B), X2.2.2b
unnamed: U2.24 (OUT4B), X2.2.4b
unnamed: U2.25 (OUT3B), X2.2.3b

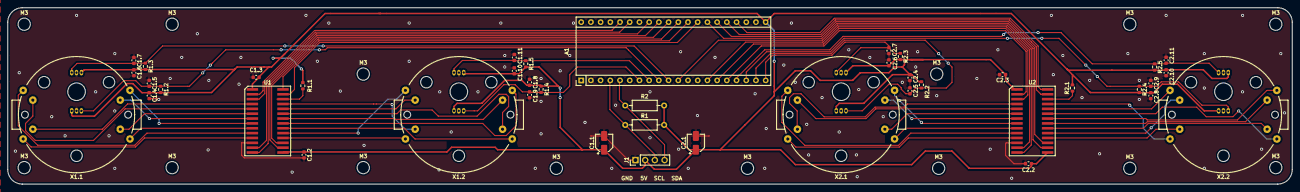
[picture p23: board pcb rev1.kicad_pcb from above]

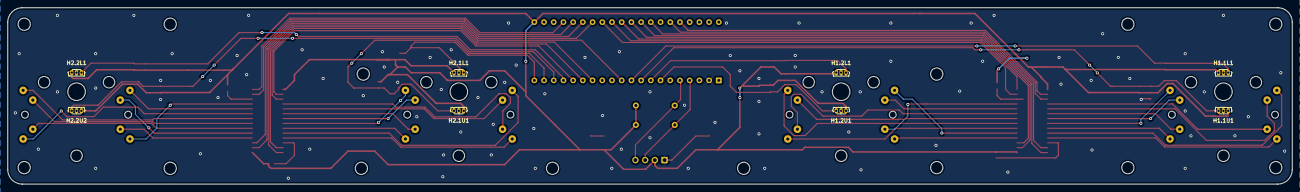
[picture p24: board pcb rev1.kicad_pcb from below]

Board: 2 copper layers, 336.0 x 46.1 mm, 64 parts (8 on the bottom side), 62 nets.

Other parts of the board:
M3, M3#2, M3#3, M3#4, M3#5, M3#6, M3#7, M3#8, M3#9, M3#10, M3#11, M3#12, M3#13, M3#14: MountingHole_3.2mm_M3
